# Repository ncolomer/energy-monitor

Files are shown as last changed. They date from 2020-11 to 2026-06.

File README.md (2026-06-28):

# energy-monitor

> energy-monitor module
> installed energy-monitor module
> connections of energy-monitor module

> “You can't improve what you don't measure”

This project is a DIY module + a [Rust](https://www.rust-lang.org/) application that aims at measuring grid consumption metrics, display collected values on an OLED display, and send them to an external InfluxDB database and/or [Home Assistant](https://www.home-assistant.io/) (over MQTT) for storage and monitoring.

The module was designed to fit any European-standard distribution boards (same form factor as a circuit breaker) and has 90mm (5-module) width.
It does not collect data directly but rather fetches metrics from [Lechacal](http://lechacal.com/)'s [RPICT](http://lechacal.com/wiki/index.php?title=Raspberrypi_Current_and_Temperature_Sensor_Adaptor) module and Enedis [Linky](https://fr.wikipedia.org/wiki/Linky) electric meter (France national power provider).

I built this project to observe and store my own energy consumption, to eventually improve it. And, well... also because it looked a cool DIY project (it actually was!).

⚠️ My electrical installation has three-phase power supply. Even though the project could run on one-phase power supply, it might also need some adaptation. Any contribution welcome!



**Table of contents**

* [Application](#application)
  - [Interface](#interface)
  - [Installation](#installation)
  - [Configuration](#configuration)
* [Hardware](#hardware)
  - [Parts](#parts)
  - [Wiring](#wiring)
  - [Enclosure](#enclosure)
* [Photo gallery](#photo-gallery)

## Application

This project includes a Rust application that handles everything, from I/O to display.

### Interface

The user interface is composed of several pages that can be cycled using the push button (like a carousel).

#### Startup screen

> startup screen

This screen displays the project logo, connection statuses and the current application version.
It is shown at application startup and also belongs to the page carousel (last position).

Connection statuses are shown only for configured components (sources are always shown):
- RPICT
  RPICT status, white square means connected.
- Linky
  Linky status, white square means connected.
- InfluxDB
  InfluxDB status, white square means connected.
- Home Assistant
  Home Assistant (MQTT) status, white square means connected.

#### Instantaneous metrics screen (RPICT)

> rpict screen

This screen displays instantaneous metrics measured from the RPICT:
- **lines apparent power** value with a gauge that shows the max seen value since boot
- sum of consumed **lines power**
- mean of lines **RMS voltage**

It is the first displayed screen when waking up from sleep.

#### Cumulated metrics screens (Linky)

> linky screen

This screen displays instantaneous metrics collected from the Linky:
- Linky's counter **unique id**
- "heures creuses" and "heures pleines" **indices**, used for billing

### Installation

To run the energy-monitor application on a Raspberry Pi Zero W:
- install a fresh [Raspberry Pi OS](https://www.raspberrypi.org/software/operating-systems/) on a SD card
- insert the SD card and open a terminal (desktop or ssh)
- configure the system to enable SPI and UART via the [`raspi-config`](https://www.raspberrypi.org/documentation/configuration/raspi-config.md) helper
- ensure user `pi` belongs to group `spi`, `gpio` and `dialout` using command `usermod -aG spi,gpio,dialout pi`
- download energy-monitor binary from the [Github Release](https://github.com/ncolomer/energy-monitor/releases) section
- run the application with the `energy-monitor` binary.
  You can override configuration using YAML config file or environment variables.
  See [Configuration](#configuration) section below for a full list of overridable settings.

```
$ energy-monitor -h
A tool to measure, display and store electrical consumption metrics.

Usage: energy-monitor [OPTIONS]

Options:
  -c, --config <FILE>  Sets a custom YAML config file
  -h, --help           Print help
  -V, --version        Print version
```

For advanced users:
- use a systemd service to launch the application at system startup

### Configuration

You can configure the application either by providing a YAML config file (see `-c --config <FILE>` binary arg) or using environment variables:

| YAML path | Environment variable | Description | Default |
|---|---|---|---|
| `log_level` | `APP__LOG_LEVEL` | Application log level | `INFO` |
| `hmi.sleep_timeout_secs` | `APP__HMI__SLEEP_TIMEOUT_SECS` | Duration in seconds before shutting down display | `30` |
| `hmi.max_line_power_watts` | `APP__HMI__MAX_LINE_POWER_WATTS` | Max expected line power in watts | `6900` |
| `hmi.button_debounce_ms` | `APP__HMI__BUTTON_DEBOUNCE_MS` | Push button debounce duration in milliseconds | `100` |
| `hmi.button_bcm_pin` | `APP__HMI__BUTTON_BCM_PIN` | Push button BCM pin number | `27` |
| `serial.rpict` | `APP__SERIAL__RPICT` | Serial port for RPICT | `/dev/ttyAMA0` |
| `serial.linky` | `APP__SERIAL__LINKY` | Serial port for uTeleinfo (Linky) | `/dev/ttyUSB0` |
| `influxdb.host` | `APP__INFLUXDB__HOST` | InfluxDB host | _(disabled)_ |
| `influxdb.port` | `APP__INFLUXDB__PORT` | InfluxDB port | `8086` |
| `influxdb.database` | `APP__INFLUXDB__DATABASE` | InfluxDB database | `metrology` |
| `influxdb.prefix` | `APP__INFLUXDB__PREFIX` | Application's measures prefix | _(none)_ |
| `hassmqtt.host` | `APP__HASSMQTT__HOST` | Home Assistant MQTT broker host | _(disabled)_ |
| `hassmqtt.port` | `APP__HASSMQTT__PORT` | Home Assistant MQTT broker port | `1883` |
| `hassmqtt.username` | `APP__HASSMQTT__USERNAME` | MQTT username (optional) | _(none)_ |
| `hassmqtt.password` | `APP__HASSMQTT__PASSWORD` | MQTT password (optional) | _(none)_ |
| `hassmqtt.discovery_prefix`| `APP__HASSMQTT__DISCOVERY_PREFIX`| Home Assistant MQTT discovery prefix | `homeassistant`|

`influxdb` and `hassmqtt` are optional, **independent** sinks — both are **disabled by default**. Enable either, both, or neither by providing its block (a sink's nested fields, e.g. `influxdb.port`, only apply once its block is present).

When `hassmqtt` is configured, the application registers its sensors in Home Assistant through [MQTT Discovery](https://www.home-assistant.io/integrations/mqtt/#mqtt-discovery) (no manual YAML needed). The Linky "heures creuses"/"heures pleines" indexes are exposed as `total_increasing` energy sensors, so they can be used directly in the [Energy dashboard](https://www.home-assistant.io/docs/energy/electricity-grid/). The current tariff period (`ptec`) is exposed as an `enum` sensor (`HC`/`HP`) to drive tariff-based automations.

## Hardware

The module is composed of several parts listed in the [Parts](#parts) section.
Electronics parts (push button, OLED display and RPICT) are wired to the Raspberry Pi, see [Wiring](#wiring) section.
RPICT is tied to the Raspberry Pi module via 29.7mm Brass Standoffs, they are both tied to enclosure's part 1 via clips.
The OLED display is tied to enclosure's part 3 the same way.

### Parts

The following table presents the partlist needed to build a full module:

| Part | Quantity | Price  | Links |
|---|---|---|---|
| **Raspberry** Pi Zero WH | 1 | 14.60€ | [buy](https://www.kubii.fr/cartes-raspberry-pi/2076-raspberry-pi-zero-wh-kubii-3272496009394.html) |
| 5V 3A Micro USB Power Supply | 1 | 2.30€  | [buy](https://www.aliexpress.com/item/33000487854.html) |
| **Sandisk** Micro SD card 16GB Class 10 | 1 | 9.90€  | [buy](https://www.kubii.fr/raspberry-pi-microbit/2587-carte-micro-sd-sandisk-16go-classe10-taux-de-transfert-80mb-kubii-619659161613.html) |
| **Waveshare** 2.23" OLED Display 128×32 Pixels SPI/I2C | 1 | 23.00€ | [buy](https://www.amazon.fr/dp/B07XDXZ74V) / [doc](https://www.waveshare.com/wiki/2.23inch_OLED_HAT) |
| **LeChacal** RPIZ CT3V1 | 1 | 18.30€ | [buy](http://lechacalshop.com/gb/internetofthing/63-rpizct3v1.html) / [doc](http://lechacal.com/wiki/index.php/RPIZ_CT3V1) |
| **LeChacal** EU AC/AC Adaptor | 1 | 15.00€ | [buy](http://lechacalshop.com/gb/internetofthing/29-acac-adaptor-voltage-sensor-for-rpict-series.html) |
| 3pcs SCT-013-000 Current Transformer | 1 | 11.30€ | [buy](https://www.aliexpress.com/item/32708887594.html) |
| 3pcs 6x6x4.3MM 4PIN G89 Push Button | 1 | 0.70€  | [buy](https://www.aliexpress.com/item/32669948621.html) |
| 200pcs M2.5 Brass Standoffs | 1 | 9.90€  | [buy](https://www.amazon.fr/gp/product/B07QHZNZWD) |
| (optional) **Charles** Micro Teleinfo V2.0 | 1 | 22.90€ | [buy](https://www.tindie.com/products/hallard/micro-teleinfo-v20/) / [doc](http://hallard.me/category/tinfo/) |
| (optional) 3pcs Micro USB to USB 2.0 adapter | 1 | 5.00€  | [buy](https://www.amazon.fr/gp/product/B00YOX4JU6) |

Total price is roughly 130€, not counting shipping.

### Wiring

The following tables uses the following Raspberry Pi pinout as reference:

> raspberry pi pinout reference

In order to achieve wiring between parts, you may need the following tools/parts:

| Part | Price  | Link |
|---|---|---|
| 22AWG Electrical Wire box | 11.80€ | [buy](https://www.aliexpress.com/item/32872439317.html) |
| 620pcs Dupont Connector kit 1 | 4.00€  | [buy](https://www.aliexpress.com/item/4000645340712.html) |
| 310pcs Dupont Connector kit 1 | 4.00€  | [buy](https://www.aliexpress.com/item/4000570942676.html) |
| SN-28B Pin Crimping Tool | 4.00€  | [buy](https://www.aliexpress.com/item/33048867532.html) |

#### RPICT

| RPICT | Raspberry Pi | Physical |
|---|---|---|
| 1 | 3.3 | 1 |
| 6 | GND | 6 |
| 8 | GPIO14 (UART0_TXD) | 8 |
| 10 | GPIO15 (UART0_RXD) | 10 |

#### OLED display

| OLED | Raspberry Pi | Physical | BCM |
|---|---|---|-----|
| VCC  | 3.3 | 17 | - |
| GND  | GND | 20 | - |
| DIN  | MOSI | 19 | 10  |
| CLK  | SCLK | 23 | 11  |
| CS | CE0 | 24 | 8 |
| D/C  | GPIO5 | 18 | 24  |
| RES  | GPIO6 | 22 | 25  |

#### Push button

| Push Button | Raspberry Pi | Physical | BCM |
|---|---|---|-----|
| 1 | GPIO27 | 13 | 27  |
| 4 | GND | 14 | - |

### Enclosure

> print plate
> module cad front
> module cad back

The enclosure contains 3 clippable parts so that it is easier and faster to print on a 3D printer. 
Assembly only needs a bit of epoxy to hold the push button in place. Don't forget to place the 3D-printed button before glueing the push button!
The enclosure was designed using [Autodesk Fusion 360](https://www.autodesk.com/products/fusion-360).

You can find `emonitor-part*.stl` STL files in the project's [`enclosure`](https://github.com/ncolomer/energy-monitor/tree/main/enclosure) directory.

I printed mine in 6 hours, using [PrusaSlicer](https://www.prusa3d.com/prusaslicer/) as slicer, and with the following parameters:
- 0.20mm SPEED profile
- 20% infill
- support on build plate only
- white 1.75mm PLA filament

Notes:
- don't forget to print the button in your favorite color, see `button.stl` STL file
- I also designed an enclosure for utinfo, see `uteleinfo-part*.stl` STL files

## Photo gallery

> linky's teleinfo connector
> utinfo gateway
> push button cable
> module components
> module inside once mounted

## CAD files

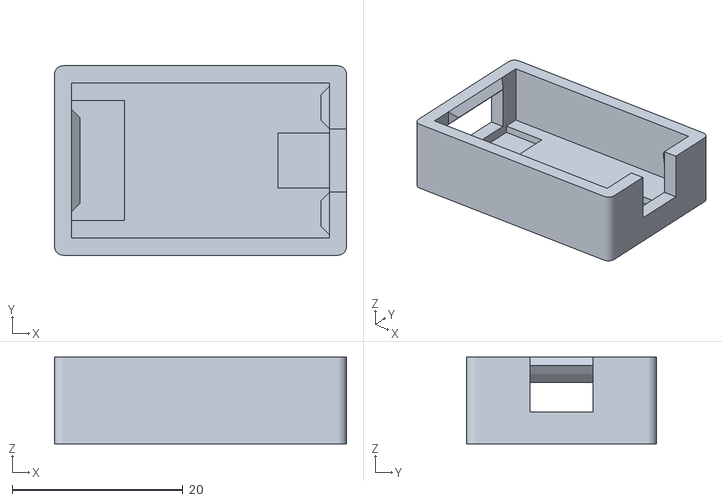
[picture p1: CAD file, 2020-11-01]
enclosure/uteleinfo-part1.stl
34.2 x 22.2 x 10.1

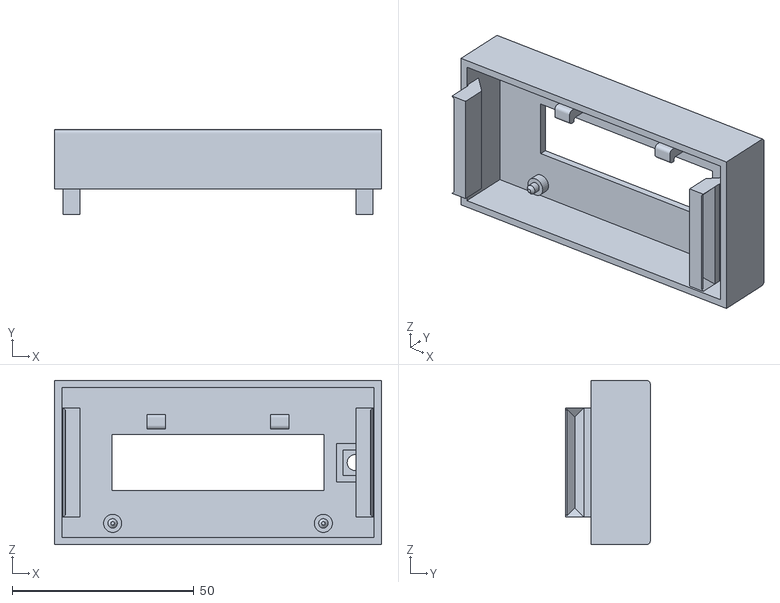
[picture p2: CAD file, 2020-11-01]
enclosure/emonitor-part3.stl
90.0 x 23.3 x 45.2

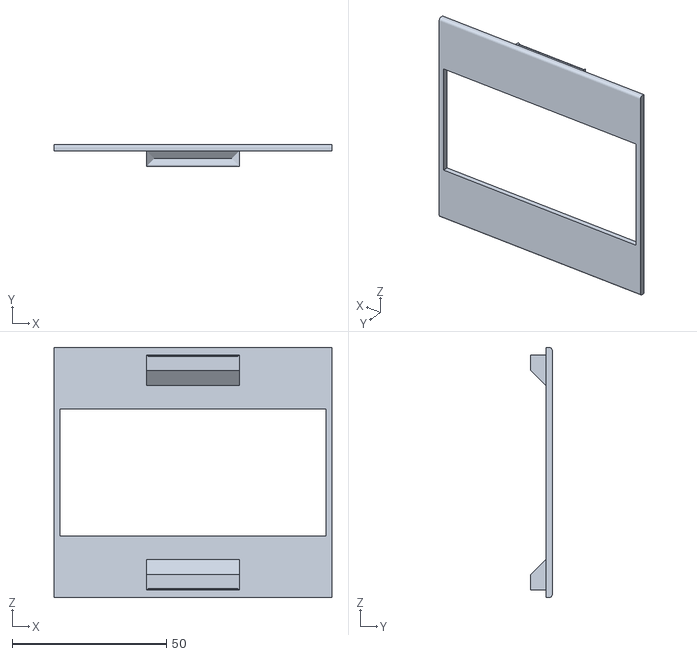
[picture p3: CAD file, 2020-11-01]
enclosure/emonitor-part2.stl
90.0 x 7.00 x 81.0

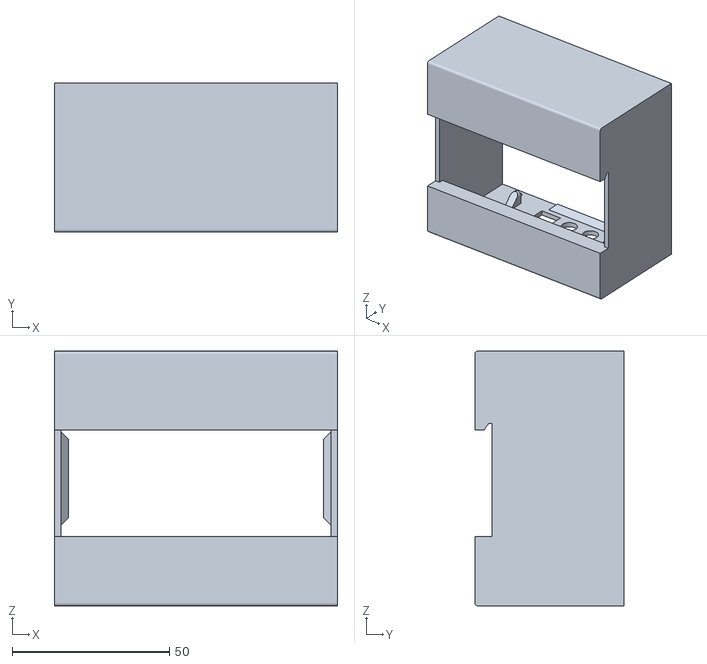
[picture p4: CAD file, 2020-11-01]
enclosure/emonitor-part1.stl
90.0 x 47.5 x 81.0

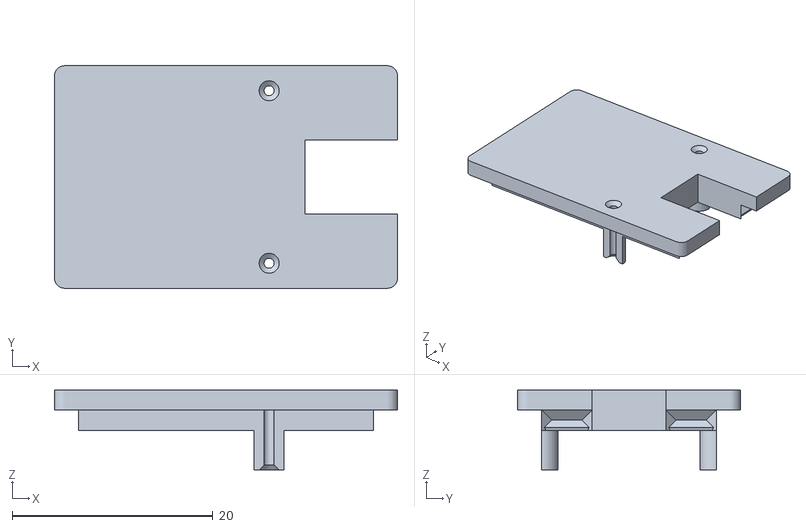
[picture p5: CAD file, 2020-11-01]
enclosure/uteleinfo-part2.stl
34.2 x 22.2 x 7.95

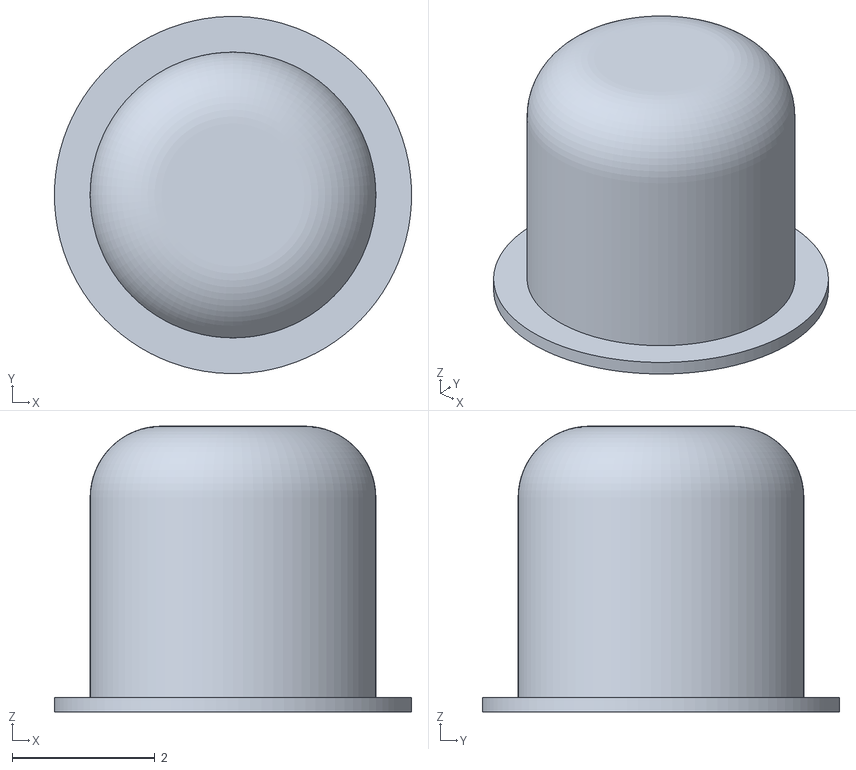
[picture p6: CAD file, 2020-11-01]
enclosure/button.stl
5.00 x 5.00 x 4.00

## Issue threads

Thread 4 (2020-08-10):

Add a resettable max value in line power bar graphs

ncolomer, 2020-08-10:

ncolomer, 2020-11-16:
585126b added the bar max feature, however user can't reset them.
I'd like to implement the reset with a long press on the button, when user is on the RPICT screen.

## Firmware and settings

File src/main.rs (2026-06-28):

use std::error::Error;
use std::fs;
use std::path::PathBuf;

use clap::{arg, command, value_parser};
use tokio::signal;

use energy_monitor::actor::datalogger::DataLoggerActor;
use energy_monitor::actor::hmi::HmiActor;
use energy_monitor::actor::linky::LinkyActor;
use energy_monitor::actor::rpict::RpictActor;
use energy_monitor::settings::Settings;

#[tokio::main]
async fn main() -> Result<(), Box<dyn Error>> {
    let matches = command!()
        .arg(
            arg!(-c --config <FILE> "Sets a custom YAML config file")
                .required(false)
                .value_parser(value_parser!(PathBuf)),
        )
        .get_matches();
    let config_file = matches
        .get_one::<PathBuf>("config")
        .map(|path| fs::read_to_string(path).unwrap());
    let settings = Settings::new(config_file).expect("Can't load settings");
    env_logger::Builder::new().parse_filters(&settings.log_level).init();
    log::debug!("{:?}", settings);

    let rpict = RpictActor::create(&settings.serial.rpict);
    let linky = LinkyActor::create(&settings.serial.linky);
    let datalogger = DataLoggerActor::create(&settings.influxdb, &settings.hassmqtt, &rpict, &linky)?;
    let hmi = HmiActor::create(
        &settings.hmi,
        &rpict,
        &linky,
        &datalogger,
        settings.influxdb.is_some(),
        settings.hassmqtt.is_some(),
    )?;
    log::info!("energy-monitor started");

    let _ = signal::ctrl_c().await;
    log::info!("energy-monitor stopping");
    hmi.shutdown().await;
    Ok(())
}

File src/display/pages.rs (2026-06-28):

use std::fmt::Debug;

use embedded_graphics::{
    image::{Image, ImageRaw},
    mono_font::{ascii::*, MonoTextStyle},
    pixelcolor::BinaryColor,
    prelude::*,
    primitives::{PrimitiveStyle, Rectangle},
    text::{Alignment, Text},
};

use crate::display::icons::*;
use crate::display::widgets::*;
use crate::driver::linky::TariffPeriod;

#[derive(Debug, Eq, PartialEq, Copy, Clone)]
pub enum Page {
    Startup,
    Rpict,
    Linky,
}

#[derive(Clone, Debug, PartialEq)]
pub struct StartupPage {
    is_rpict_connected: bool,
    is_linky_connected: bool,
    influxdb: Option<bool>,
    hassmqtt: Option<bool>,
    version: String,
}

impl StartupPage {
    pub fn new(version: &str, influxdb_enabled: bool, hassmqtt_enabled: bool) -> Self {
        let version = version.to_string();
        Self {
            is_rpict_connected: false,
            is_linky_connected: false,
            influxdb: influxdb_enabled.then_some(false),
            hassmqtt: hassmqtt_enabled.then_some(false),
            version,
        }
    }

    pub fn rpict_status(&mut self, is_connected: bool) {
        self.is_rpict_connected = is_connected;
    }

    pub fn linky_status(&mut self, is_connected: bool) {
        self.is_linky_connected = is_connected;
    }

    pub fn influxdb_status(&mut self, is_connected: bool) {
        self.influxdb = self.influxdb.map(|_| is_connected);
    }

    pub fn hassmqtt_status(&mut self, is_connected: bool) {
        self.hassmqtt = self.hassmqtt.map(|_| is_connected);
    }
}

impl Drawable for StartupPage {
    type Color = BinaryColor;
    type Output = ();

    fn draw<D>(&self, target: &mut D) -> Result<Self::Output, D::Error>
    where
        D: DrawTarget<Color = Self::Color>,
    {
        target.clear(BinaryColor::Off)?;

        const CENTER: Point = Point::new(128 / 2, 32 / 2);
        const LOGO_OFFSET: Point = Point::new(0, -4);
        const VERSION_OFFSET: Point = Point::new(46, 10);

        Rectangle::with_center(CENTER + LOGO_OFFSET - Point::new(0, 2), Size::new(90, 15))
            .into_styled(PrimitiveStyle::with_stroke(BinaryColor::On, 1))
            .draw(target)?;

        Text::with_alignment(
            "energy-monitor",
            CENTER + LOGO_OFFSET,
            MonoTextStyle::new(&FONT_6X12, BinaryColor::On),
            Alignment::Center,
        )
        .draw(target)?;

        let mut icons: Vec<&ImageRaw<'static, BinaryColor>> = Vec::new();
        icons.push(if self.is_rpict_connected { &*RPICT_ON } else { &*RPICT_OFF });
        icons.push(if self.is_linky_connected { &*LINKY_ON } else { &*LINKY_OFF });
        if let Some(connected) = self.influxdb {
            icons.push(if connected { &*INFLUXDB_ON } else { &*INFLUXDB_OFF });
        }
        if let Some(connected) = self.hassmqtt {
            icons.push(if connected { &*HASS_ON } else { &*HASS_OFF });
        }
        for (i, icon) in icons.into_iter().enumerate() {
            Image::new(icon, Point::new(20 + 10 * i as i32, 20)).draw(target)?;
        }

        Text::with_alignment(
            &format!("v{}", self.version),
            CENTER + VERSION_OFFSET,
            MonoTextStyle::new(&FONT_4X6, BinaryColor::On),
            Alignment::Right,
        )
        .draw(target)?;
        Ok(())
    }
}

#[derive(Clone, Debug, PartialEq)]
pub struct RpictPage {
    l1_sparkline: SparkLine,
    l2_sparkline: SparkLine,
    l3_sparkline: SparkLine,
    total_apparent_power: f32,
    avg_vrms: f32,
}

impl RpictPage {
    pub fn new(max_power: f32) -> Self {
        Self {
            l1_sparkline: SparkLine::new(Point::new(1, 6), "P1".to_string(), max_power),
            l2_sparkline: SparkLine::new(Point::new(1, 14), "P2".to_string(), max_power),
            l3_sparkline: SparkLine::new(Point::new(1, 22), "P3".to_string(), max_power),
            total_apparent_power: 0.0,
            avg_vrms: 0.0,
        }
    }

    pub fn update(
        &mut self,
        l1_apparent_power: f32,
        l2_apparent_power: f32,
        l3_apparent_power: f32,
        l1_vrms: f32,
        l2_vrms: f32,
        l3_vrms: f32,
    ) {
        self.l1_sparkline.update(l1_apparent_power);
        self.l2_sparkline.update(l2_apparent_power);
        self.l3_sparkline.update(l3_apparent_power);
        self.total_apparent_power = l1_apparent_power + l2_apparent_power + l3_apparent_power;
        self.avg_vrms = (l1_vrms + l2_vrms + l3_vrms) / 3.0;
    }
}

impl Drawable for RpictPage {
    type Color = BinaryColor;
    type Output = ();

    fn draw<D>(&self, target: &mut D) -> Result<Self::Output, D::Error>
    where
        D: DrawTarget<Color = Self::Color>,
    {
        target.clear(BinaryColor::Off)?;

        self.l1_sparkline.draw(target)?;
        self.l2_sparkline.draw(target)?;
        self.l3_sparkline.draw(target)?;

        let text_style = MonoTextStyle::new(&FONT_5X7, BinaryColor::On);

        Text::with_alignment(
            &format!("= {:4.1}kW", self.total_apparent_power / 1000.0),
            Point::new(1, 30),
            text_style,
            Alignment::Left,
        )
        .draw(target)?;

        Text::with_alignment(
            &format!("{:5.2}V", self.avg_vrms),
            Point::new(127, 30),
            text_style,
            Alignment::Right,
        )
        .draw(target)?;

        Ok(())
    }
}

#[derive(Clone, Debug, PartialEq)]
pub struct LinkyPage {
    adco: String,
    hchp: Option<u32>,
    hchc: Option<u32>,
    ptec: TariffPeriod,
}

#[allow(clippy::new_without_default)]
impl LinkyPage {
    pub fn new() -> Self {
        Self {
            adco: "?".to_string(),
            hchp: None,
            hchc: None,
            ptec: TariffPeriod::Unknown,
        }
    }

    pub fn update(&mut self, adco: String, hchp: u32, hchc: u32, ptec: TariffPeriod) {
        self.adco = adco;
        self.hchp = Some(hchp);
        self.hchc = Some(hchc);
        self.ptec = ptec;
    }
}
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

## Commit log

2020-11-01 Update enclosure STL files
    [button.stl, emonitor-part1.stl, emonitor-part2.stl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]
2020-11-12 Add dedicated thread pool for each subscriber (#7)
    * Add dedicated thread pool for each subscribe
    Fixes #3
    * Add subscription lock mechanism + proper thread name + log
2020-11-13 Use Adafruit's SSD1305 driver (#8)
    * Use adafruit's Adafruit_CircuitPython_SSD1305 library for display
    https://github.com/adafruit/Adafruit_CircuitPython_SSD1305
    * Use correct pins
2020-11-13 Remove unused (and unfunctional) button held feature
2020-11-13 Better code structure (#9)
    * Pass a name when subscribing to dispatcher
    * Log services initialized as debug
    * Improve code structure + handle max bar
    * Fix typos
    * Add landing page
    * Fix tuple errors and adjust offsets
    * Better name
2020-11-14 Add Linky support (#11)
    * Add linky device
    * Move up landing page
    * Increase button bounce time
    * Rework linky page
    * Reset carousel on wakeup
    * Enable linky at startup
    * Dynamic selector in linky page
    * Remove linky mock
    * Safe start of rpict and linky drivers
    * Write linky measurements into influxdb
    * Fix linky serial configuration
    * Fix linky points fields name when sending to influxdb
    * Handle unknow fields that come from linky
    * Cast values as int
2021-12-29 Connectivity icons (#16)
    * Use python module's main
    * Add status icons
    * Better init DataLogger
    * Pin to Python 3.7
    * Fix startup script
    * Adjust landing page
    * Update README.md
    * Load interface first
2023-03-13 Rewrite project in Rust (#19)
    * Remove python stuff
    * Update .gitignore file
    * Add project rust files
    * Add build GA workflow
    * Fix clippy warnings
    * Update cli infos
    * Rename yaml extension into yml
    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
    [button.rs]
2023-03-13 Minor improvements and code cleaning (#23)
    * Improve logging
    * Rename landing occurrences into startup
    * Rename wifi occurrences into influxdb
    * Rename internal variables
    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
2026-06-28 Fix README enclosure link to use main branch
2026-06-28 Add Home Assistant MQTT sink (#32)
    * Add Home Assistant MQTT sink
    Publish collected rpict/linky metrics to Home Assistant via MQTT
    Discovery, alongside the existing InfluxDB sink. Each sink is enabled
    independently by the presence of its config block.
    - new service::hassmqtt module: retained discovery configs (re-announced
    on every reconnect and on the HA birth message), MQTT last-will
    availability, correct device/state classes (total_increasing/Wh for the
    Linky energy indexes so they fit the Energy dashboard), non-blocking
    publish so a dead broker never stalls the data logger
    - DataLoggerActor owns the optional HassMqttClient; per-source publish +
    status tracking collapsed into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
    [influxdb.rs, linky.rs, main.rs]
